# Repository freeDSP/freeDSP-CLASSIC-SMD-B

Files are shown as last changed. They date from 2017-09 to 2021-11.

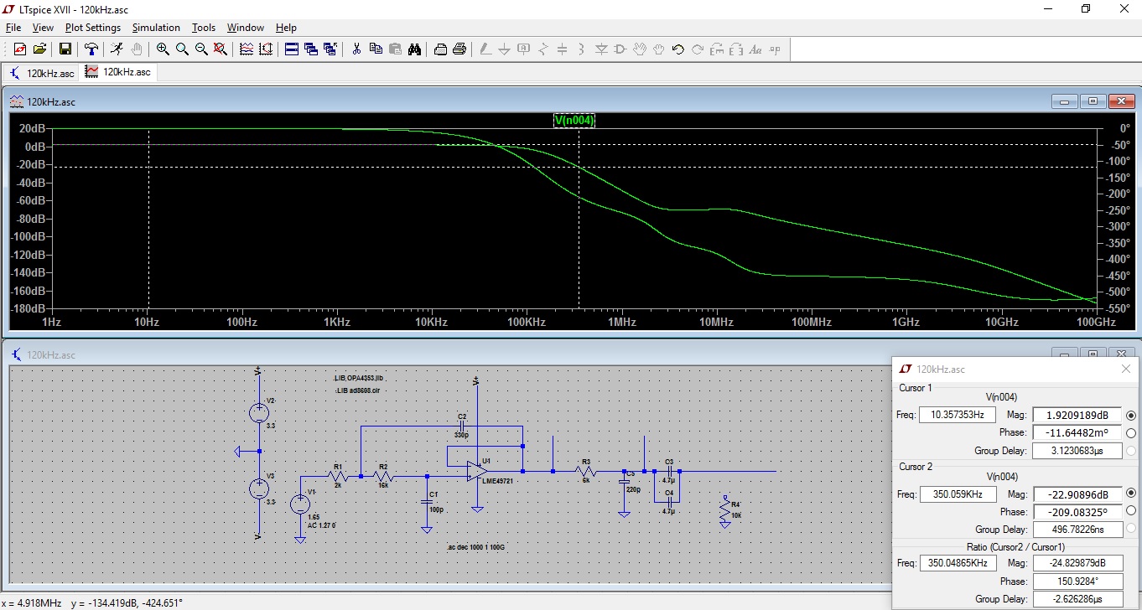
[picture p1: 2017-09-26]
Simulations/Filter/120kHz Grenzfrequenz/Bilder/120kHz_3order_bessel_LM49721.jpg

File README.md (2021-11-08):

# freeDSP CLASSIC SMD

BOARD STATUS: READY TO BE BUILT

SMD update of the freeDSP CLASSIC.

LICENCE: Creative Commons Attribution Share-Alike 4.0 license

http://freedsp.cc

## About

The freeDSP is an open-source digital signal processor family for the do-it-yourself community. The applications range from active loudspeaker concepts (digital crossovers, bass enhancement, ...) and room equalization over advanced musical effect processors to car audio signal processing. 

This _freeDSP Classic SMD-B_ is a updated SMD version of the original _freeDSP Classic_ with a few improvements/changes.
This board has been designed using the Cross-Platform Open Source Tool [KiCad](http://kicad.org/).

More informations kann be found on the [freeDSP website](http://freedsp.cc)

You can find a PDF version of the schematic in the SOURCES folder (freeDSP_Classic_SMD.pdf)

## Links

#### FreeDSP Website
[http://freedsp.cc/](http://freedsp.cc)

#### Documentation
[Google Doc](https://docs.google.com/document/d/1K3joEg4iIRMazfqGLaVoBdybitr4o_KIVZfQ-qeNDzs/edit?usp=sharing)

#### FreeDSP Guidelines
https://github.com/freeDSP/WIKI-AND-GENERAL-TOPICS/wiki/freeDSP-Guidelines

## Git usage

#### How to setup local repository
- Change to your FreeDSP directory
- Clone the repository (including submodule)  
 `git clone --recursive https://github.com/freeDSP/freeDSP-CLASSIC-SMD-B.git`
- Change to the newly created Classic-SMD-B directory
- Checkout a branch for the library submodule, if you want to modify it as well
  `git submodule foreach 'git checkout 'master''`
- Open the project file in KiCad

#### How to update the local copy
- To update the project  
  `git pull`
- To update the library  
  `git submodule update --remote --merge`

#### To commit and push local changes
- If you modified something in the LIBRARY folder, change to the LIBRARY folder and run  
  `git add .` (Only required if files were added)  
  `git commit -am "Message"`  (Describe what you changed)  
- Change to the project root directory and run
  `git add .` (Only required if files were added)  
  `git commit -am "Message"`  (Describe what you changed)    
- In the project directory run  
  `git push --recurse-submodule=on-demand`  

#### Define alias to make things shorter
- In the project directory run
  `git config alias.supdate 'submodule update --remote --merge'`  
  `git config alias.spush 'push --recurse-submodules=on-demand'`  
- Afterwards you can use `git supdate` to update the submodule and `git spush` to push any commited changes  

#### Other useful commands
- `git status`  
  Shows general information about the current branch, uncommited changes, not yet added new files and more
- `git diff`  
  Shows uncommited changes
- `git reset --hard origin/master`
  Reset all files to the current status of the dev-hs-01 branch on the Github repository  
  **Careful** This deletes all local changes, so make sure all changes you made and you do not want to delete are pushed to the remote repository

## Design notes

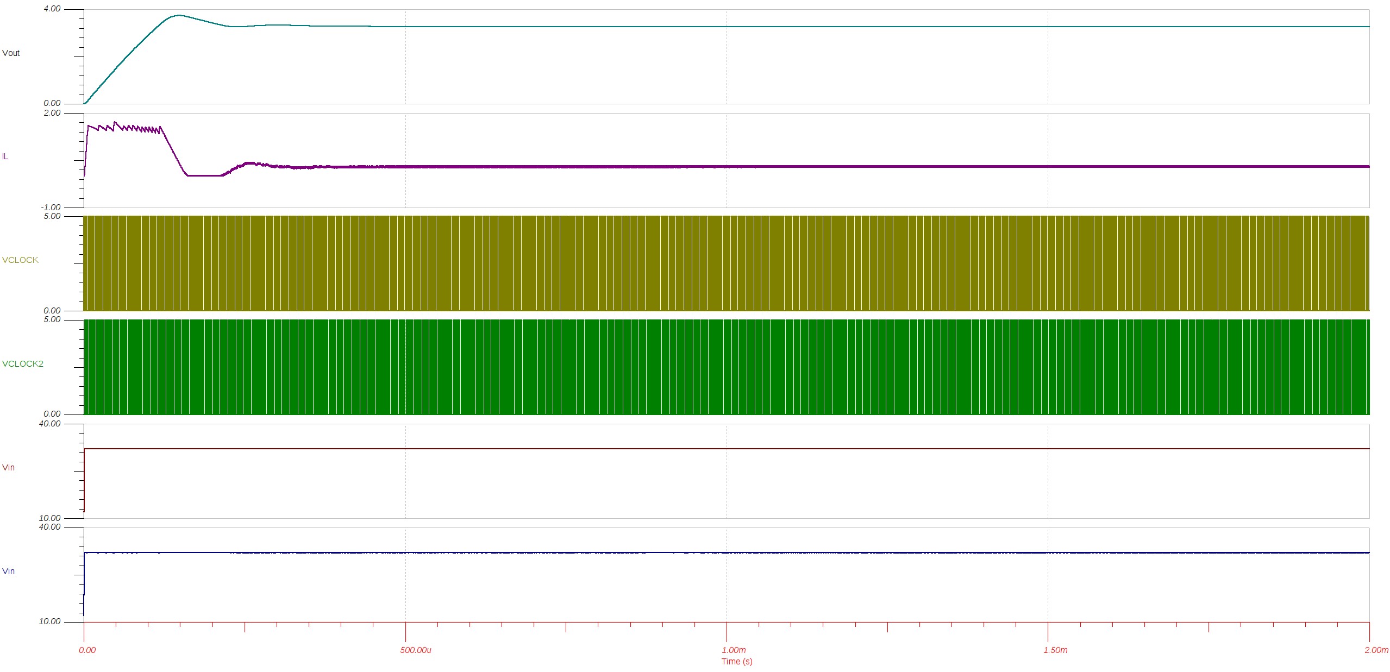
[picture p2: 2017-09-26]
Simulations/SwitchingRegulator/LM2841x/steady_300mA.jpg

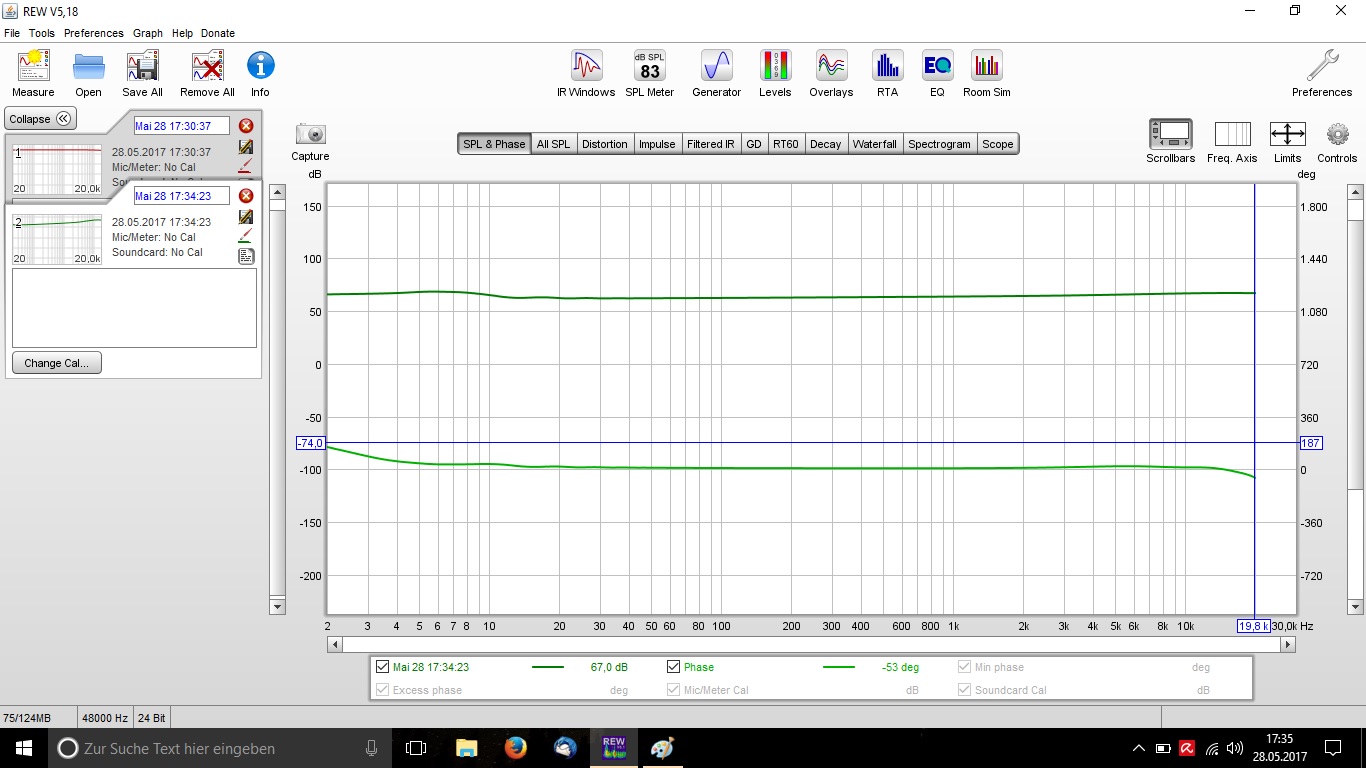
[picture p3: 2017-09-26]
Simulations/Filter/Messungen LME49721/Bode_LME49721.jpg

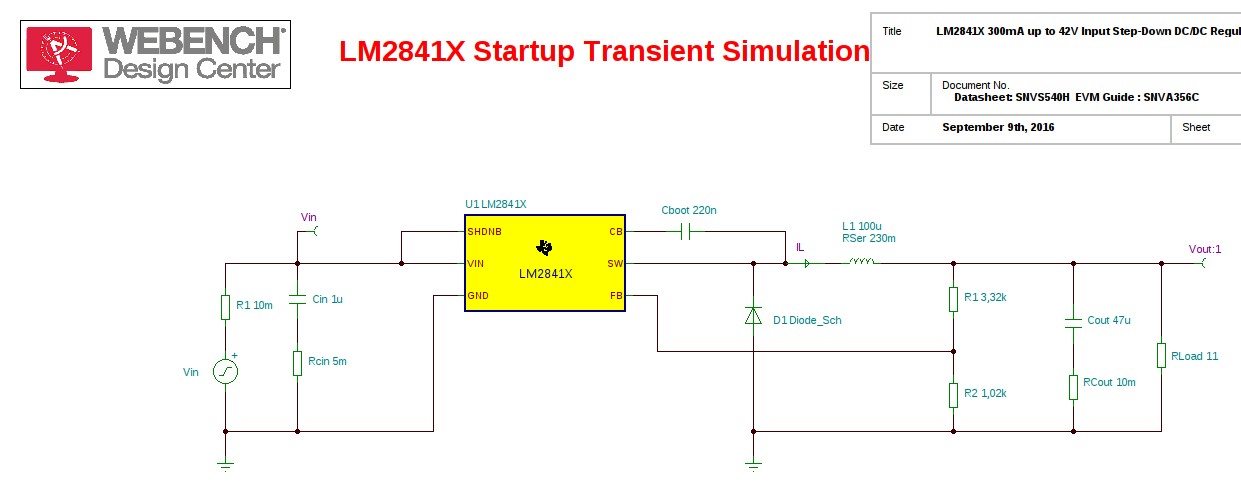
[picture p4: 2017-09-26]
Simulations/SwitchingRegulator/LM2841x/lm2841x.JPG

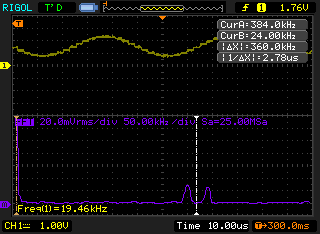
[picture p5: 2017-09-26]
Simulations/Spiegelfrequenzen_ADAU1701/Spiegelfrequenzen_Classic.bmp

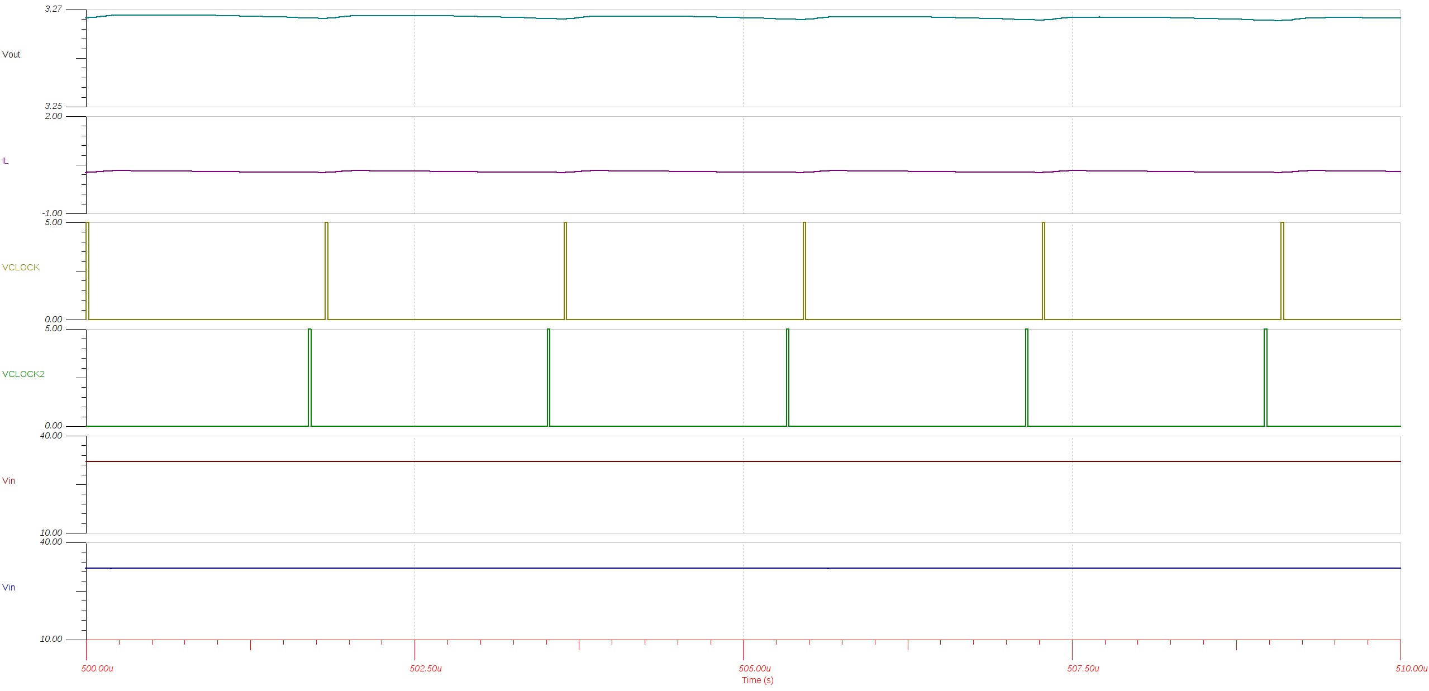
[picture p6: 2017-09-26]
Simulations/SwitchingRegulator/LM2841x/steady_300mA-zoomed.jpg

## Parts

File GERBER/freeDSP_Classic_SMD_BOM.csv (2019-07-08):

ID | Bezeichner | Gehäuse | Stückzahl | Bezeichnung | Anbieter und Referenz
1 | P7,P4,P6,P5 | IDC_Header_Straight_16pins | 4 | STDCONN
2 | P12,P10,P11,P13 | Pin_Header_Straight_2x03 | 4 | CONN_02X03
3 | P3 | IDC_Header_Straight_10pins | 1 | CONN_02X05
4 | C1,C3,C4,C6,C8,C9,C10,C11,C13,C16,C17,C40,C41,C47,C48,C50,C51,C52,C53,C55 | C_1206_HandSoldering | 20 | 100n
5 | C12,C15,C54 | C_1206_HandSoldering | 3 | 10u
6 | C18 | C_1206_HandSoldering | 1 | 3n3
7 | C19 | C_1206_HandSoldering | 1 | 56n
8 | C20,C21,C22,C23 | C_1206_HandSoldering | 4 | 100p
9 | C24,C25,C26,C27 | C_1206_HandSoldering | 4 | 330p
10 | C28,C29,C30,C31 | C_1206_HandSoldering | 4 | 5.6n
11 | C32,C33,C34,C35,C36,C37,C45,C2,C5,C7,C14 | C_Radial_D5_L11_P2 | 11 | 10u
12 | C38,C39 | C_Radial_D5_L11_P2 | 2 | 47u
13 | C46 | C_1206_HandSoldering | 1 | 10n
14 | C49 | C_Radial_D5_L11_P2 | 1 | 2.2u
15 | Cboot1 | C_1206_HandSoldering | 1 | 220n
16 | Cin1 | C_1206_HandSoldering | 1 | 2u2
17 | Cout1 | C_1206_HandSoldering | 1 | 47u
18 | C_res1,C_res3 | C_Radial_D5_L11_P2 | 2 | x
19 | C_res2 | C_1206_HandSoldering | 1 | x
20 | D1,D2,D3,D5 | SMA | 4 | B150
21 | D4 | SMB | 1 | P6SMB 27V
22 | D6,D7,D8,D9,D10 | SOD-123W | 5 | 1N4148
23 | FB1,FB2 | C_0805_HandSoldering | 2 | 330
24 | J1,J2,J4,J5,J6,J7 | RCA_RCJ-01x | 6 | RCA_01
25 | J3 | RIACON101-2 | 1 | CONN_01X02
26 | L1 | Choke_SMD_6.0x5.8 | 1 | 47u
27 | LM1 | SOT23-6_1.7x3.0mm_Pitch0.95mm | 1 | LM284x
28 | P1 | Pin_Header_Straight_1x06 | 1 | CONN_01X06
29 | P2 | Pin_Header_Straight_1x03 | 1 | CONN_01X03
30 | P8,P9 | Pin_Header_Straight_2x03 | 2 | CONN_02X03
31 | R1,R2,R3,R4,R5,R7 | R_1206_HandSoldering | 6 | 10K
32 | R6 | R_1206_HandSoldering | 1 | 1K
33 | R8 | R_1206_HandSoldering | 1 | 18K
34 | R9,R10,R38,R39 | R_1206_HandSoldering | 4 | 10k
35 | R11 | R_1206_HandSoldering | 1 | 475
36 | R12,R13,R14,R15 | R_1206_HandSoldering | 4 | 2k
37 | R16,R17,R18,R19 | R_1206_HandSoldering | 4 | 16k
38 | R20,R21,R22,R23,R48 | R_1206_HandSoldering | 5 | 330
39 | R24,R25,R26,R27,R28,R29 | R_1206_HandSoldering | 6 | 49k9
40 | R30,R33 | R_1206_HandSoldering | 2 | 7k
41 | R31,R34 | R_1206_HandSoldering | 2 | 8k
42 | R32,R35 | R_1206_HandSoldering | 2 | 18k
43 | R36,R41,R42 | R_1206_HandSoldering | 3 | 1k
44 | R37 | R_1206_HandSoldering | 1 | 390k
45 | R40 | R_1206_HandSoldering | 1 | 1M
46 | R43 | R_1206_HandSoldering | 1 | 470k
47 | R44,R45,R46,R47 | R_1206_HandSoldering | 4 | 24
48 | Rfb1 | R_1206_HandSoldering | 1 | 3.32k
49 | Rfb2 | R_1206_HandSoldering | 1 | 1.02k
50 | U1 | LQFP-48_7x7mm_Pitch0.5mm | 1 | ADAU1701
51 | U2 | SOIC-8_3.9x4.9mm_Pitch1.27mm | 1 | 24AA256SN
52 | U3,U4 | SOIC-8_3.9x4.9mm_Pitch1.27mm | 2 | LME49721
53 | U5 | DCT | 1 | SN74LVC3G14
54 | U6 | SOIC-8_3.9x4.9mm_Pitch1.27mm | 1 | LM393
55 | U7 | SOIC-8_3.9x4.9mm_Pitch1.27mm | 1 | IDT2305NZ
56 | X1 | Oscillator_SMD_Abracon_ASV-4pin_7.0x5.1mm_HandSoldering | 1 | ASV-24.576MHz-EJ-T
57 | Q1,Q2,Q3,Q4,Q18 | SOT-23_Handsoldering | 5 | BSS123
58 | Q6,Q7,Q8,Q9,Q10,Q11,Q12,Q13 | SOT-23_Handsoldering | 8 | BSH103,215
59 | Q14,Q15,Q16,Q17 | SOT-23_Handsoldering | 4 | MMBF5434
60 | SW1 | SW_PUSH_6mm | 1 | SW_PUSH
61 | D11 | R_1206_HandSoldering | 1 | LED
62 | Q5 | SOT-223 | 1 | FZT751TA

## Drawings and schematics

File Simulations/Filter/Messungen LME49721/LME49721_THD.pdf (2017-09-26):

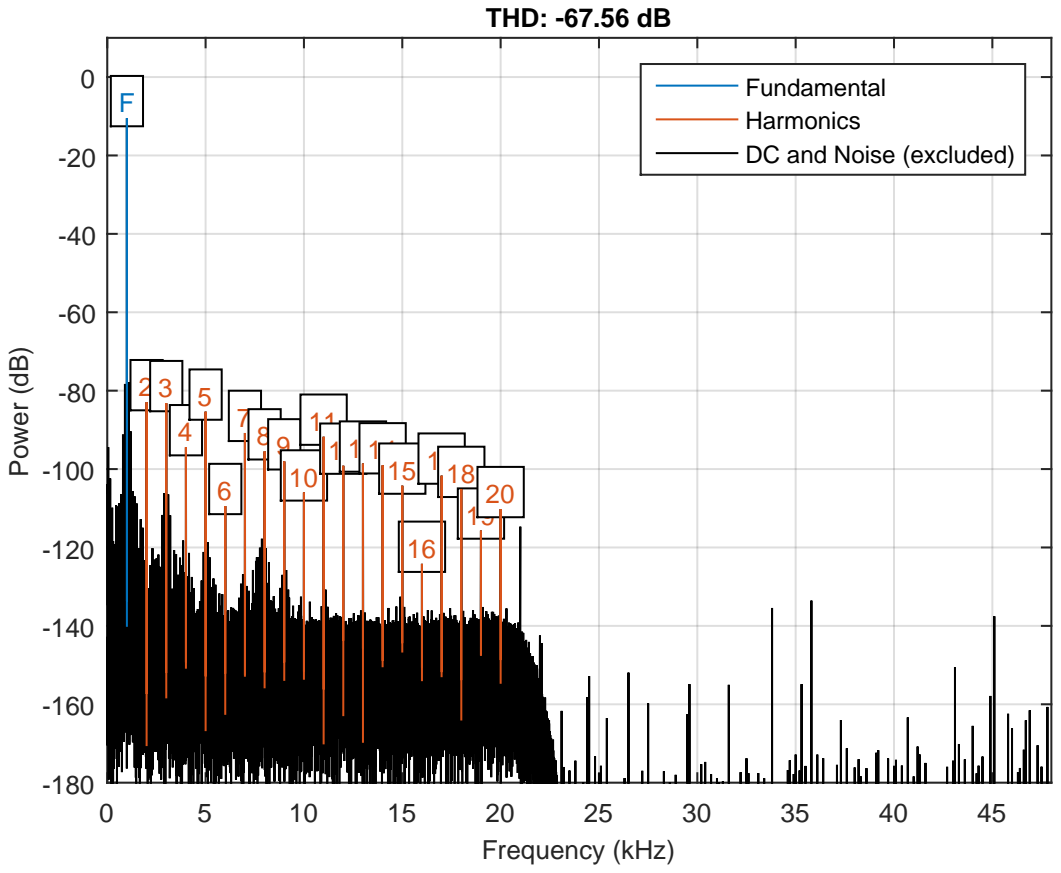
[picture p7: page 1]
Frequency (kHz); Power (dB); THD: -67.56 dB

Fundamental
Harmonics
DC and Noise (excluded)

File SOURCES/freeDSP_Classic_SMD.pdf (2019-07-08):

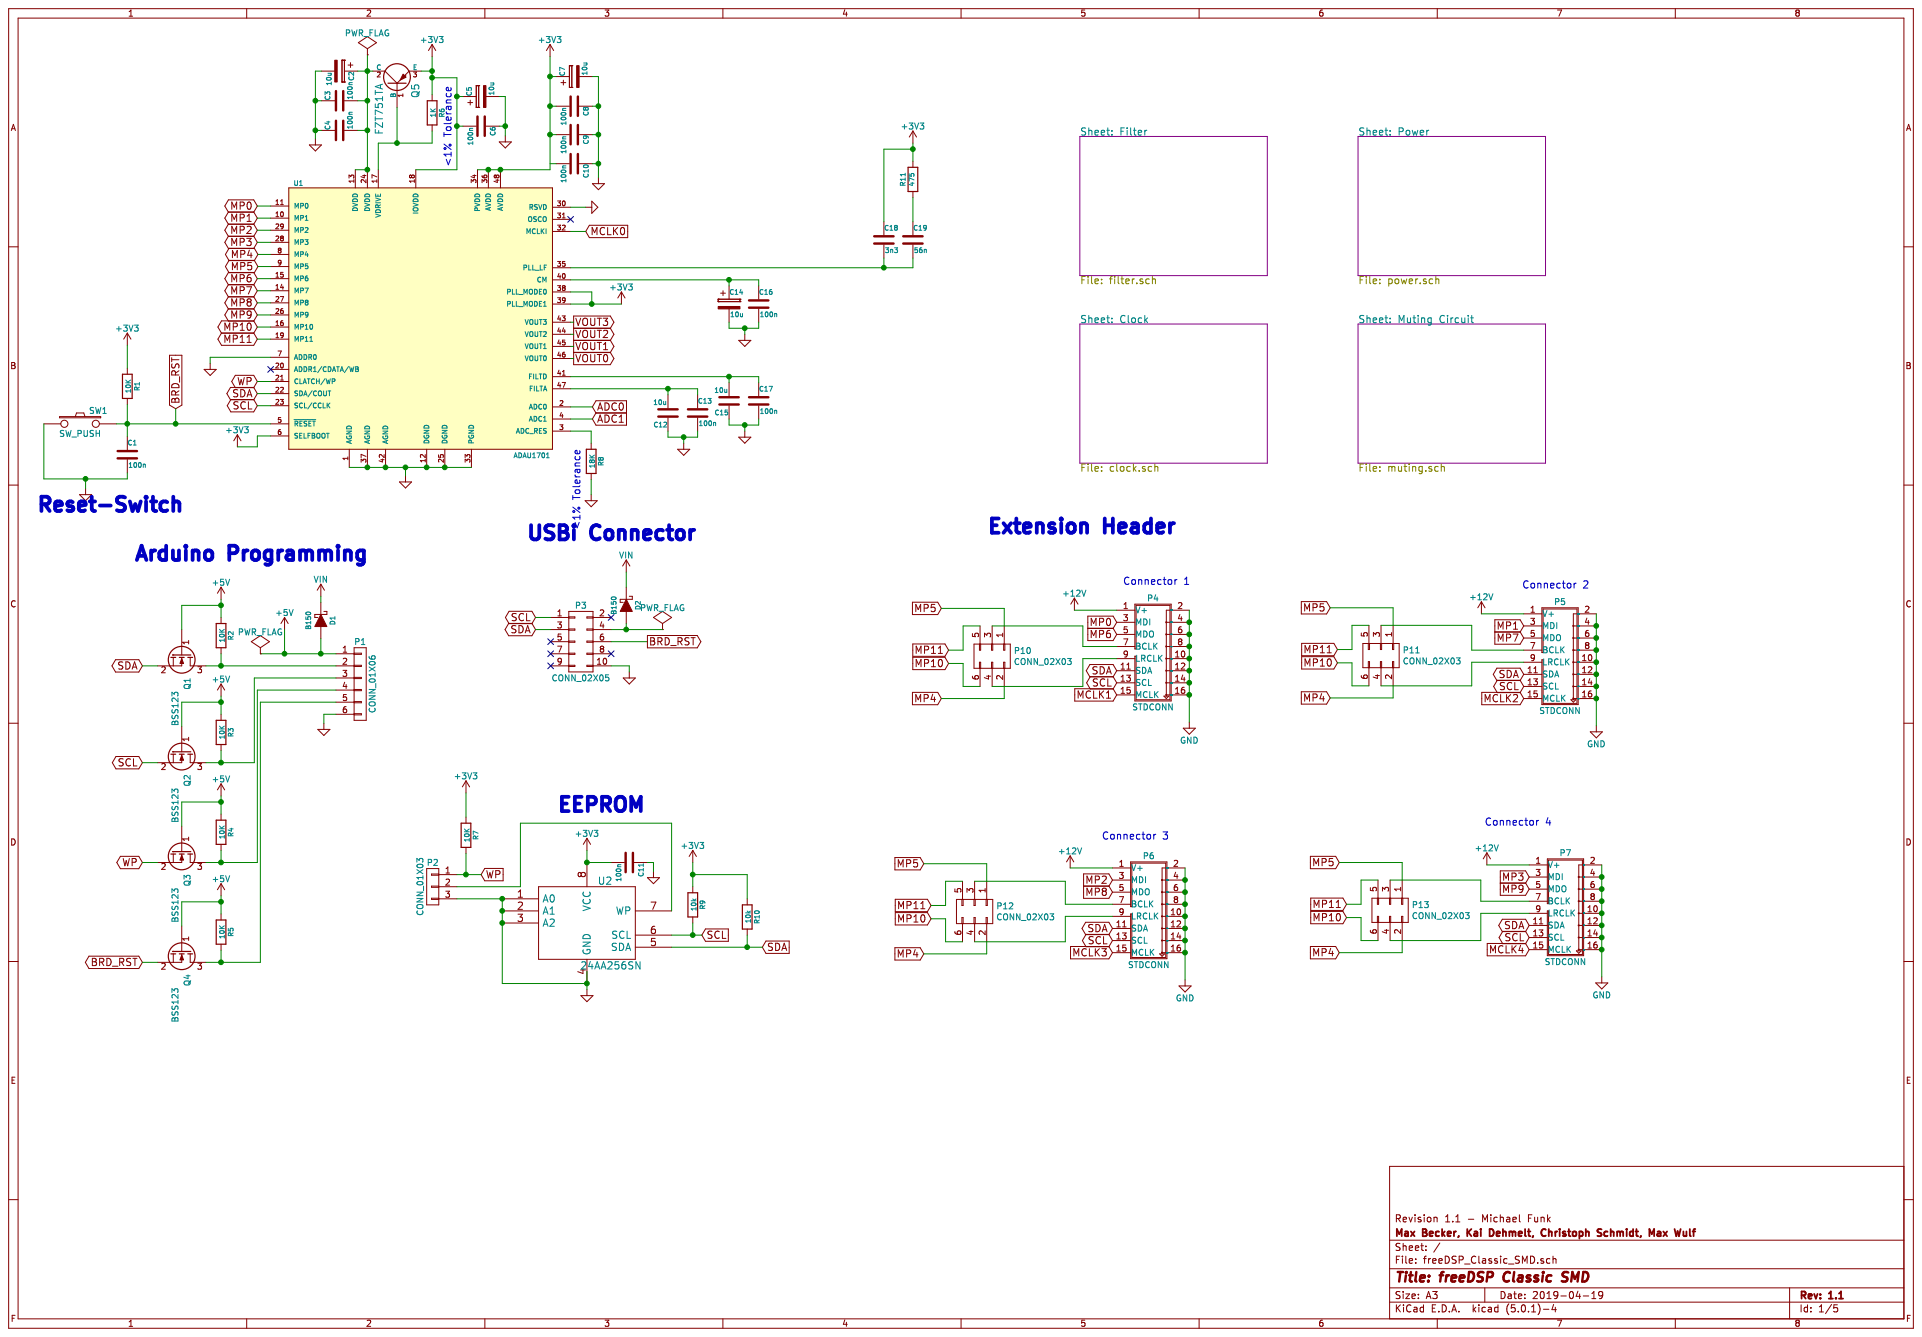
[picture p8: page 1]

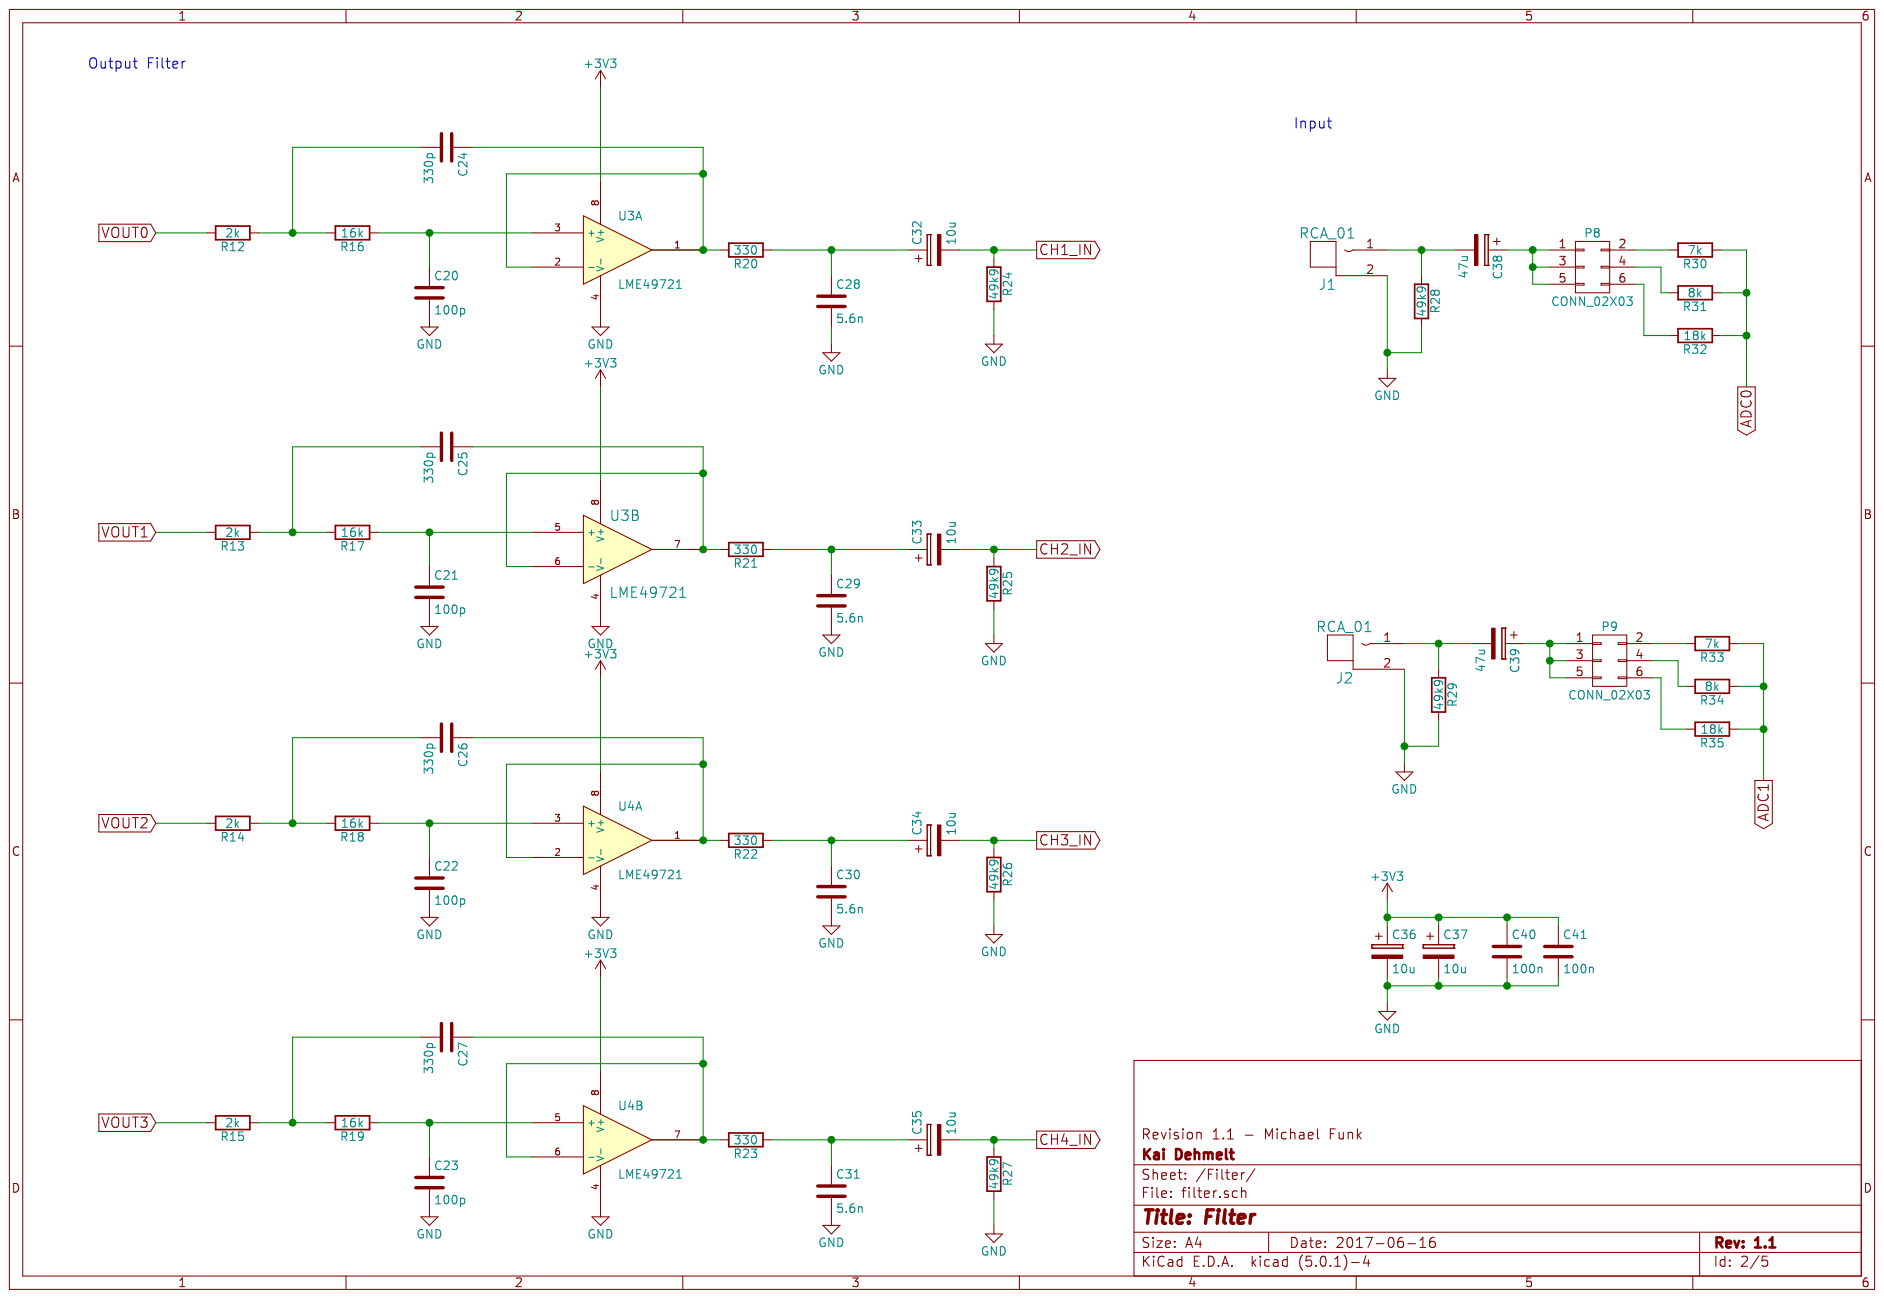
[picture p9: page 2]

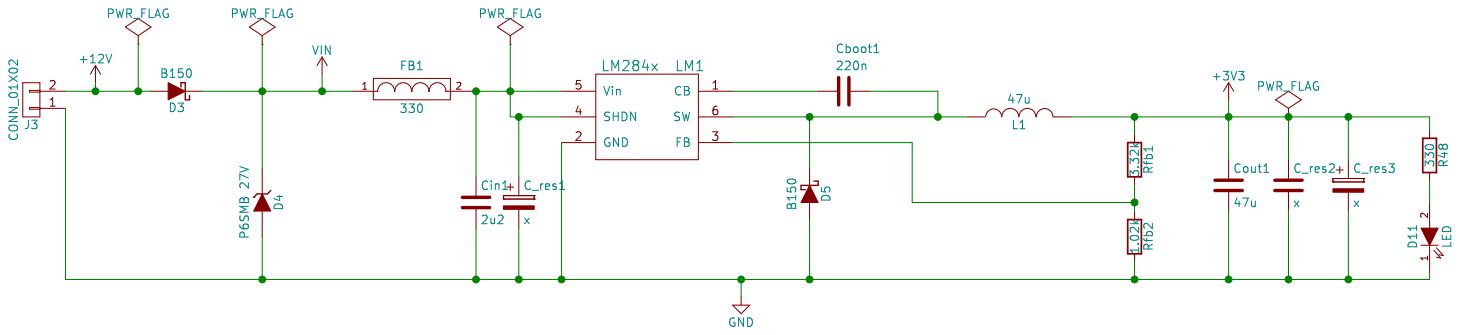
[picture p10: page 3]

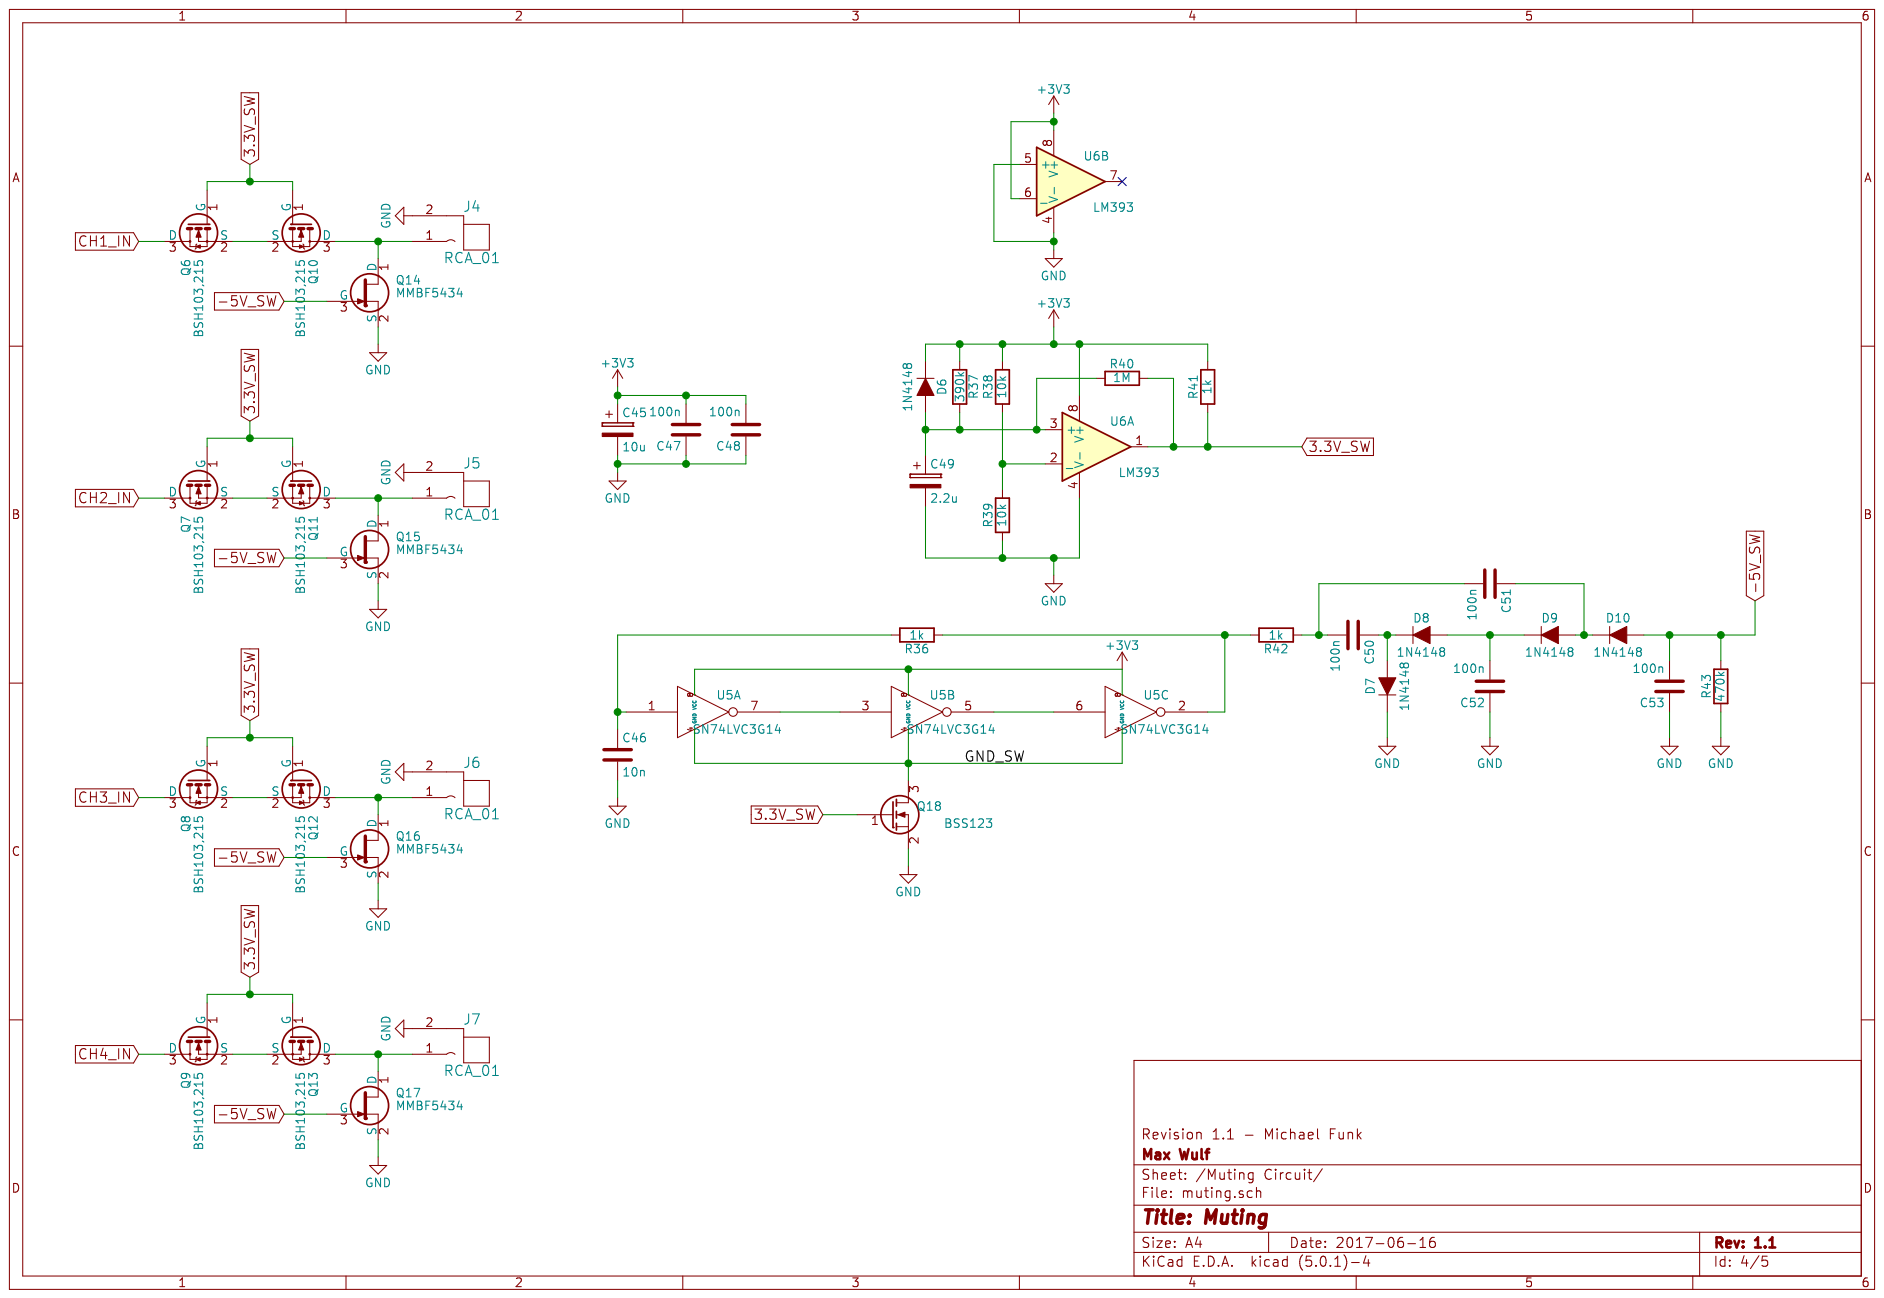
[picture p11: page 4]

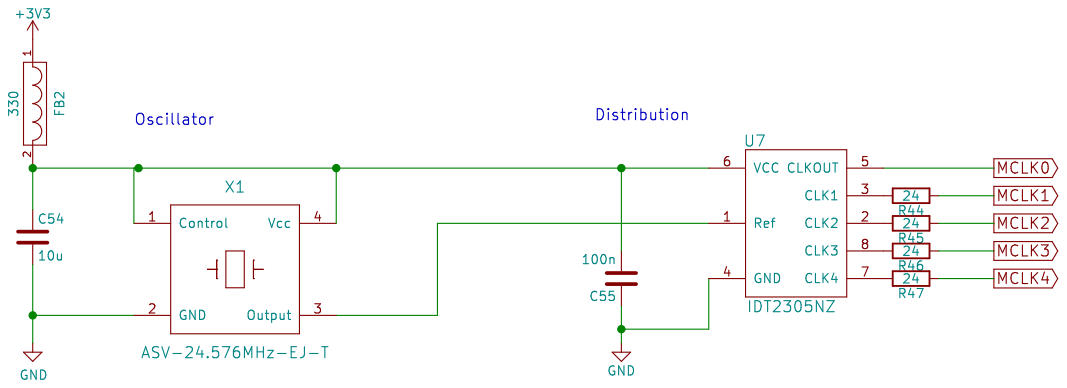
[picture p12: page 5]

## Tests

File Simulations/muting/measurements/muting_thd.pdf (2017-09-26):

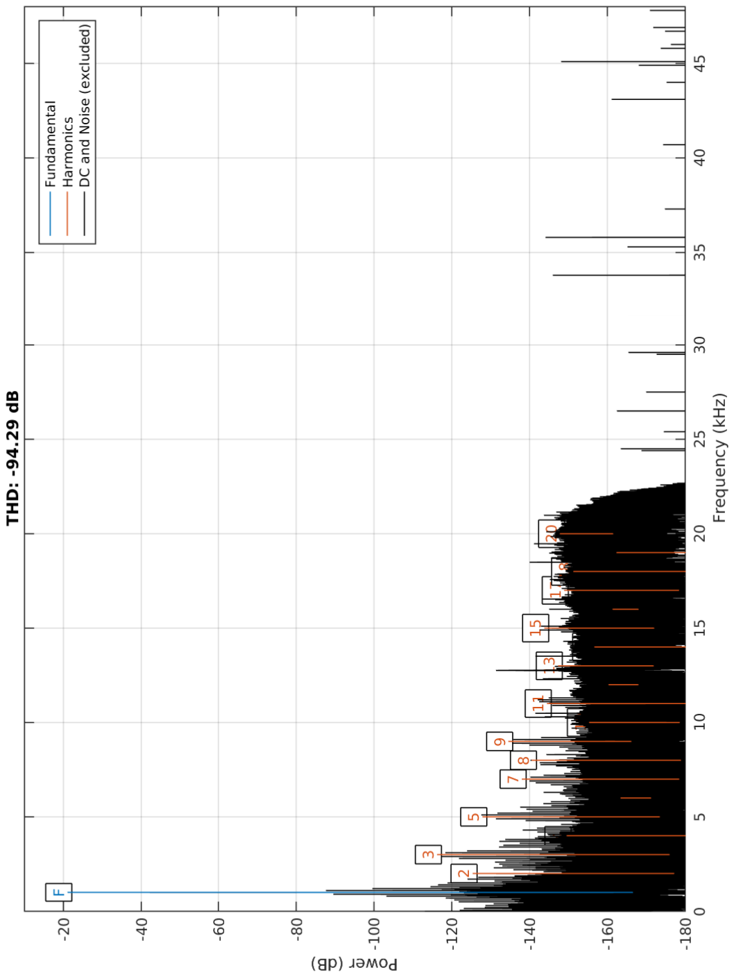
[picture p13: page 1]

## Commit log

2016-06-15 General Update
    * added fdsp-libraries
    * redid all missing connections (update to kicad4 standard-parts)
    [freeDSP_Classic_SMD.sch]
2016-07-16 * finished filter schematics, fixed some missing connections
    * next up: power supply
    [freeDSP_Classic_SMD.sch]
2017-05-03 Switched to relative library paths
    [freeDSP_Classic_SMD.sch]
2017-05-03 Updated folder structure
    [freeDSP_Classic_SMD.sch]
2017-05-16 add muting-circuit simulation files
2017-05-16 clock added
    [Clock.kicad_pcb, Clock.sch]
2017-05-17 part value options
    [Clock.sch, Dimensionierung.ods]
2017-05-17 Add KiCad schematic for muting circuit
    [muting.kicad_pcb, muting.sch]
2017-05-22 Updated muting schematics
    [muting.sch]
2017-05-28 Updated clock schematic and added footprints
    [Clock.sch, freeDSP_Classic_SMD.sch]
2017-05-28 Added schematics and more for power regulator
    [power.kicad_pcb, power.sch]
2017-05-28 Added connector to power supply
    [power.sch]
2017-05-29 filter update
    [Output_Filter.kicad_pcb, Output_Filter.sch]
2017-05-29 Updated schematics and added subcircuits to main sheet
    [clock.sch, filter.sch, freeDSP_Classic_SMD.sch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]
2017-05-29 Updated schematics
    [clock.sch, freeDSP_Classic_SMD.sch, muting.sch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]
2017-05-29 exchanged clock driver
    [Clock.sch, clock.sch]
2017-05-30 Updated schematics and labels
    [clock.sch, filter.sch, freeDSP_Classic_SMD.sch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]
2017-05-30 Assigned footprints
    [clock.sch, filter.sch, freeDSP_Classic_SMD.sch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]
2017-05-30 Add measurements for muting circuit
2017-05-31 Added new footprints
2017-05-31 updated schematic + bom + pcb start
    [clock.sch, filter.sch, freeDSP_Classic_SMD.kicad_pcb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]
2017-05-31 layout: placed some components
    [freeDSP_Classic_SMD.kicad_pcb]
2017-05-31 updated pcb
    [freeDSP_Classic_SMD.kicad_pcb, power.sch]
2017-06-01 pcb update
    [freeDSP_Classic_SMD.kicad_pcb]
2017-06-01 Filters and Muting Circuit routed
    [freeDSP_Classic_SMD.kicad_pcb]
2017-06-02 fixed switched GND Q18, placed some components
    [freeDSP_Classic_SMD.kicad_pcb, muting.sch]
2017-06-06 further routing
    [freeDSP_Classic_SMD.kicad_pcb]
2017-06-06 layout finished
    [clock.sch, freeDSP_Classic_SMD.kicad_pcb, freeDSP_Classic_SMD.sch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]
2017-06-07 added logos and gnd vias, generated gerber files
    [freeDSP_Classic_SMD-B.Cu.gbl, freeDSP_Classic_SMD-B.Mask.gbs, freeDSP_Classic_SMD-B.SilkS.gbo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]
2017-06-07 improved layout
    [clock.sch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]
2017-06-07 added schematic as pdf
2017-06-08 layout improvements
    [freeDSP_Classic_SMD.kicad_pcb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]
2017-06-11 added fiducials
    [freeDSP_Classic_SMD-B.Cu.gbl, freeDSP_Classic_SMD-B.Mask.gbs, freeDSP_Classic_SMD-B.SilkS.gbo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]
2017-06-12 some improvements
    [freeDSP_Classic_SMD.kicad_pcb, freeDSP_Classic_SMD.sch]
2017-06-12 corrected fiducials
    [freeDSP_Classic_SMD.kicad_pcb]
2017-06-12 uploaded new GERBER files
    [freeDSP_Classic_SMD.gbl, freeDSP_Classic_SMD.gbo, freeDSP_Classic_SMD.gbs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]
2017-06-16 corrected silkscreen, added schematic information
    [clock.sch, filter.sch, freeDSP_Classic_SMD.kicad_pcb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]
2017-07-05 added power led, changed via drill size
    [_saved_freeDSP_Classic_SMD.sch, _saved_power.sch, freeDSP_Classic_SMD.kicad_pcb]
2017-07-05 corrected a wire, updated GERBER
    [freeDSP_Classic_SMD-B.Cu.gbl, freeDSP_Classic_SMD-B.Mask.gbs, freeDSP_Classic_SMD-B.SilkS.gbo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]
2017-07-13 changed filter resistors, clock resistors
    [clock.sch, filter.sch]
2017-07-15 Termination resistors changed to 24Ohms
    [clock.sch]
2017-08-13 fixed wrong pinouts added some text
    [clock.sch, freeDSP_Classic_SMD.kicad_pcb]
2017-08-13 Modified FZT751
    [freeDSP_Classic_SMD.sch]
2017-08-13 Modified FZT751 Part2
    [freeDSP_Classic_SMD.kicad_pcb]
2017-08-13 Moved ADAU to correct library
    [freeDSP_Classic_SMD.sch]
2017-08-16 Fixed missing rescue library
    [clock.sch, filter.sch, freeDSP_Classic_SMD.sch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]
2017-08-16 corrected some things in layout and schematic
    [clock.sch, filter.sch, freeDSP_Classic_SMD.kicad_pcb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]
2017-08-17 Removed duplicate ADAU
    [clock.sch, filter.sch, freeDSP_Classic_SMD.sch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]
2017-08-21 updated GERBER files
    [freeDSP_Classic_SMD-B.Cu.gbl, freeDSP_Classic_SMD-B.Mask.gbs, freeDSP_Classic_SMD-B.SilkS.gbo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]
2017-08-23 Updated submodule to standard library and uploaded new schematics
2017-09-26 Update board status to 'READY TO BE BUILT'
2019-04-09 Added I2S-Solution
    Jumper für I2S Lösung hinzugefügt.
    Allerdings musste der, in den Design Rules vorgegebene Seitenabstand eingebüßt werden.
    [clock-2019-01-28-18-36-09.sch, clock-2019-02-01-18-38-43.sch, clock-2019-02-01-18-59-34.sch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]
2019-04-19 Revision Completion
    Refreshed GERBER and other manufacturing data.
    - new GEERBER
    - new schematic
    - new drill; BOM; etc.
    [clock.sch, filter.sch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]
